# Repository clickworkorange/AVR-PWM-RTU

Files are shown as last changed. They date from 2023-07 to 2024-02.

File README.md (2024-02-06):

- <a href="#description">Description</a>
- <a href="#register-map">Register map</a>
- <a href="#avr-pin-map">AVR pin map</a>
- <a href="#defaults">Defaults</a>
- <a href="#crystal-selection">Crystal selection</a>
- <a href="#schematic">Schematic</a>
- <a href="#pcb-layout">PCB layout</a>
- <a href="#the-remote-panels">The remote panels</a>
- <a href="#future">Future</a>
- <a href="#wetware-at-work">Wetware at work</a>

### Description
A Modbus and push-button controlled 4-channel PWM generator based on the Atmel ATMega328. Each channel can be set to one of four pre-defined duty cycles (0-255). In addition to being controllable by Modbus commands, the channel levels (0-3) can also be selected by means of individual push-buttons, wich increment a channel's level, wrapping at 3. The active level for each channel is output as a 2-bit value which is used to drive a set of four LEDs by means of a 74HC238 decoder. The idea is to allow for remote control of the individual channels over a three-wire interface (plus GND and VCC). The Modbus communication layer is provided by the <a href="https://github.com/mbs38/yaMBSiavr">yaMBSiavr</a> library. The code compiles to 9.3kB. 

*N.b. this is still work in progress and some features are yet to be implemented - see <a href="#future">future</a>.*

### Register map
Modbus register values are limited to a maximum value for each register; attempting to write a higher value than what is permitted for a given register will return a 03 ILLEGAL DATA VALUE response from the RTU. The same will happen if you try to write to a read only register. Writing a 1 to the last register (currently 50) will trigger a save to EEPROM of all register values - the RTU will revert to these stored values on reboot. 

#|Function|Value| |#|Function|Value
--|-------------|-----|-|--|-------------|-----
0|Ch0 Level|0-3| |26|Device ID 4-5|2 bytes
1|Ch1 Level|0-3| |27|Device ID 6-7|2 bytes
2|Ch2 Level|0-3| |28|Ch0 ID 0-1|2 bytes
3|Ch3 Level|0-3| |29|Ch0 ID 2-3|2 bytes
4|Ch0 Duty 0|0-255| |30|Ch0 ID 4-5|2 bytes
5|Ch0 Duty 1|0-255| |31|Ch0 ID 6-7|2 bytes
6|Ch0 Duty 2|0-255| |32|Ch1 ID 0-1|2 bytes
7|Ch0 Duty 3|0-255| |33|Ch1 ID 2-3|2 bytes
8|Ch1 Duty 0|0-255| |34|Ch1 ID 4-5|2 bytes
9|Ch1 Duty 1|0-255| |35|Ch1 ID 6-7|2 bytes
10|Ch1 Duty 2|0-255| |36|Ch2 ID 0-1|2 bytes
11|Ch1 Duty 3|0-255| |37|Ch2 ID 2-3|2 bytes
12|Ch2 Duty 0|0-255| |38|Ch2 ID 4-5|2 bytes
13|Ch2 Duty 1|0-255| |39|Ch2 ID 6-7|2 bytes
14|Ch2 Duty 2|0-255| |40|Ch3 ID 0-1|2 bytes
15|Ch2 Duty 3|0-255| |41|Ch3 ID 2-3|2 bytes
16|Ch3 Duty 0|0-255| |42|Ch3 ID 4-5|2 bytes
17|Ch3 Duty 1|0-255| |43|Ch3 ID 6-7|2 bytes
18|Ch3 Duty 2|0-255| |44|Slave Address|0-255
19|Ch3 Duty 3|0-255| |45|Baud Rate|0-7
20|Ch0-1 Invert|0-1| |46|Parity|0-2
21|Ch0-1 Scaler|0-7*| |47|Stop Bits|0-1
22|Ch2-3 Invert|0-1| |48|Firmware Revision|-
23|Ch2-3 Scaler|0-7*| |49|*Reserved*|
24|Device ID 0-1|2 bytes| |50|Save Settings|1/0
25|Device ID 2-3|2 bytes| | | |

\*) See the below table for the meaning of the scaler values:

**Value**|0|1|2|3|4|5|6|7
-----|----|----|----|----|----|----|----|----
**Scaler**|0|1|8|32|64|128|256|1024

Setting either of the scaler registers to zero disables those two channels. See <a href="#crystal-selection">Crystal selection</a> for the PWM frequencies resulting from the different prescalers. Note that at present changes to scalers, inversion and communication parameters requires rebooting the RTU for the changes to take effect. 

### AVR pin map

Pin|Port|Function| |Pin|Port|Function
---|----|-------------|-|---|----|-------------
1|PC6|Reset| |15|PB1|Ch0 PWM
2|PD0|RxD| |16|PB2|Ch1 PWM
3|PD1|TxD| |17|PB3|Ch2 PWM
4|PD2|Data Dir| |18|PB4|Ch3 Lvl LSB
5|PD3|Ch3 PWM| |19|PB5|Ch3 Lvl MSB
6|PD4|Load Defaults| |20|AVCC|+5V
7|Vcc|+5V| |21|AREF|n/c
8|GND|GND| |22|GND|GND
9|PB6|Xtal| |23|PC0|Ch0 Lvl LSB
10|PB7|Xtal| |24|PC1|Ch0 Lvl MSB
11|PD5|Ch2 Btn| |25|PC2|Ch0 Btn
12|PD6|Ch2 Lvl LSB| |26|PC3|Ch1 Lvl LSB
13|PD7|Ch2 Lvl MSB| |27|PC4|Ch1 Lvl MSB
14|PB0|Ch3 Btn| |28|PC5|Ch1 Btn

### Defaults
The default configuration values are: 

- Channel levels all set to 0
- Duty values for levels (all channels)
	- 0: 255
	- 1: 127
	- 2: 63
	- 3: 0
- Both scaler registers set to 4 (490 Hz @ 8 MHz)
- Communication parameters
	- Slave ID: 1
	- Baud: 9600
	- Parity: None
	- Stop bits: 1
 - Identification strings
 	- Device ID: "PWM-1"
  	- Channel IDs: "Ch0", "Ch1", "Ch2", "Ch3"

The RTU can be reset to these values at any time by holding PD4 low on power on / reset. 

### Crystal selection
It's important to pick a system clock frequency that results in the desired PWM frequency for your particular application. If you are controlling fans or other motor driven devices you'll probably want this to be outside human hearing range, if it's lights you'll want it to be high enough for persistence of vision to hide the flicker. Another consideration is the Baud-rate error that will result from choosing a system clock that is not evenly divisible by the desired communication speed. The table below shows the available PWM frequencies for a given clock and prescaler, with Baud-rate compatible clock speeds highlighted in bold: 

Xtal|1|8|32*|64|128*|256|1024
-----------|--------|--------|--------|--------|--------|--------|--------|
2.0000 MHz|7.8 kHz|980 Hz|245 Hz|123 Hz|61 Hz|31 Hz|8 Hz
**3.6864 MHz**|14.5 kHz|1.8 kHz|452 Hz|226 Hz|113 Hz|56 Hz|14 Hz
4.0000 MHz|15.7 kHz|2.0 kHz|490 Hz|245 Hz|123 Hz|61 Hz|15 Hz
**7.3728 MHz**|28.9 kHz|3.6 kHz|904 Hz|452 Hz|226 Hz|113 Hz|28 Hz
8.0000 MHz|31.4 kHz|3.9 kHz|980 Hz|490 Hz|245 Hz|123 Hz|31 Hz
16.0000 MHz|62.7 kHz|7.8 kHz|2.0 kHz|980 Hz|490 Hz|245 Hz|61 Hz
**18.4320 MHz**|72.3 kHz|9.0 kHz|2.3 kHz|1.1 kHz|565 Hz|282 Hz|71 Hz
20.0000 MHz|78.4 kHz|9.8 kHz|2.5 kHz|1.2 kHz|613 Hz|306 Hz|77 Hz

\*) Prescalers 32 & 128 are not available on Timer1, instead we get these by changing the TOP length to 10-bits / scaler 8 and 9-bits / scaler 64 respectively, and <a href="https://github.com/clickworkorange/AVR-PWM-RTU/blob/cd5e14912393d223fffba5abe3af9f1dc7a8ffb7/AVR/avr_pwm_rtu.c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">scaling the 0-255 duty value</a> accordingly. 

### Schematic
The schematic has been updated to revision 0.2 and is now presentable - you can find it in [the /KiCAD folder](https://github.com/clickworkorange/AVR-PWM-RTU/tree/main/KiCAD). There will be more changes, not least on the input side, but this should work: 
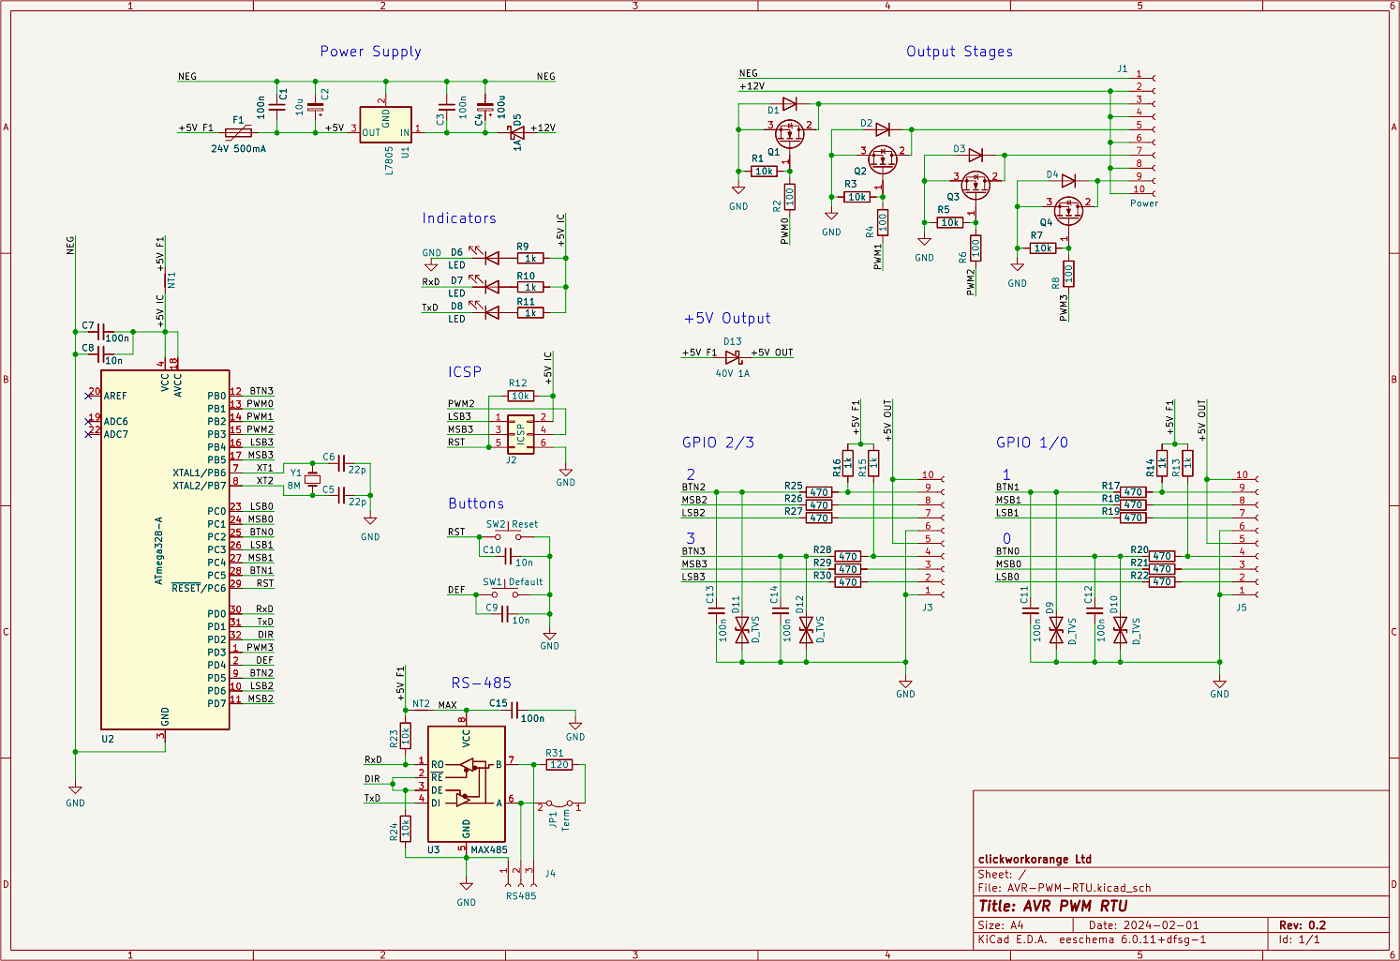
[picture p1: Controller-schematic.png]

See <a href="#the-remote-panels">below</a> for the remote panel schematic & PCB layout. 

### PCB layout
The project includes a PCB layout which is sized to fit in a 3U DIN-rail enclosure: 
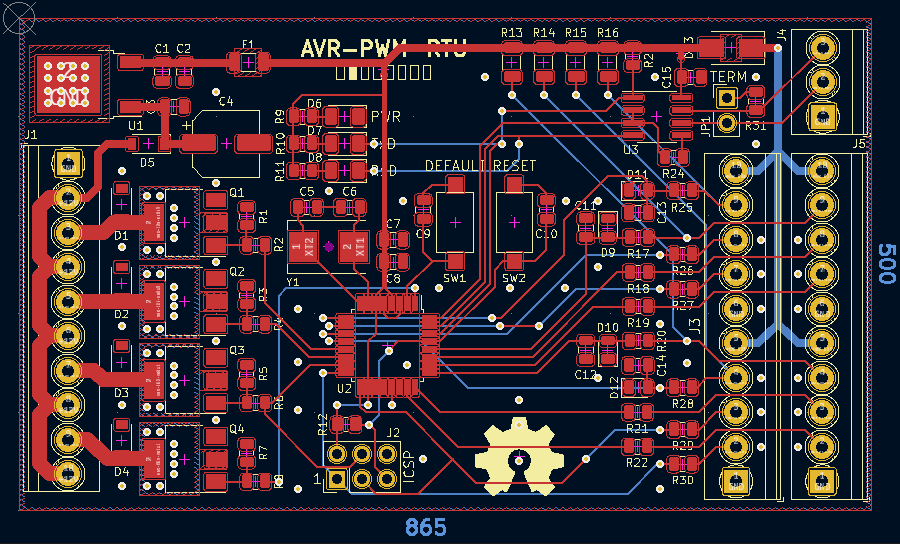
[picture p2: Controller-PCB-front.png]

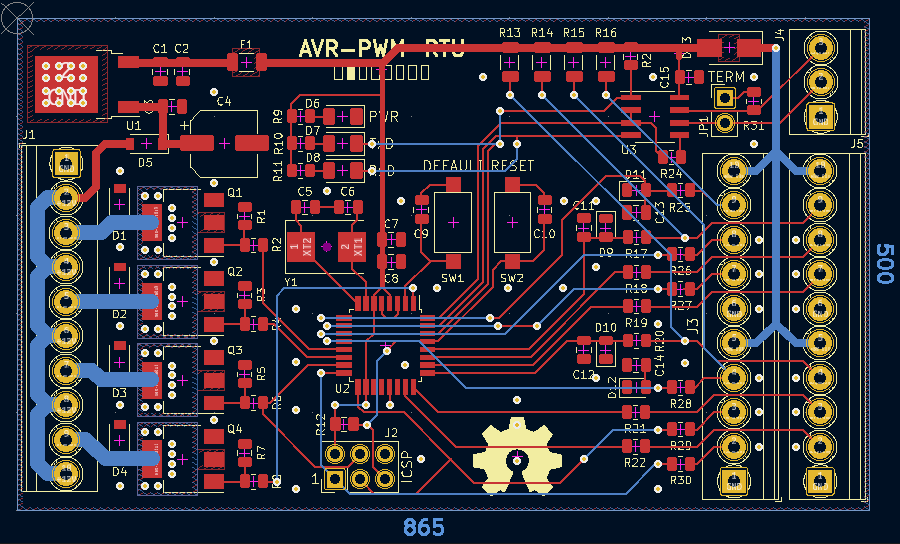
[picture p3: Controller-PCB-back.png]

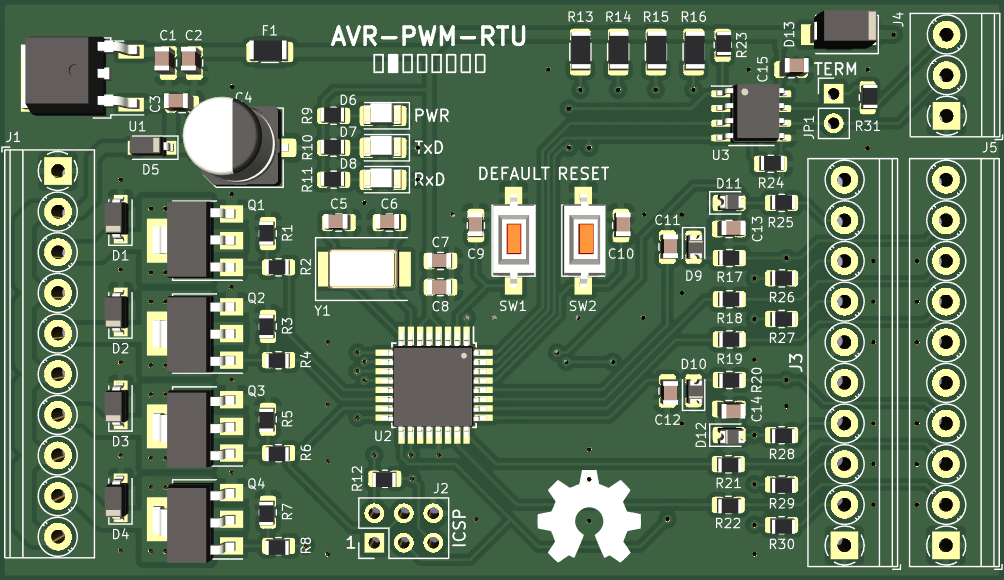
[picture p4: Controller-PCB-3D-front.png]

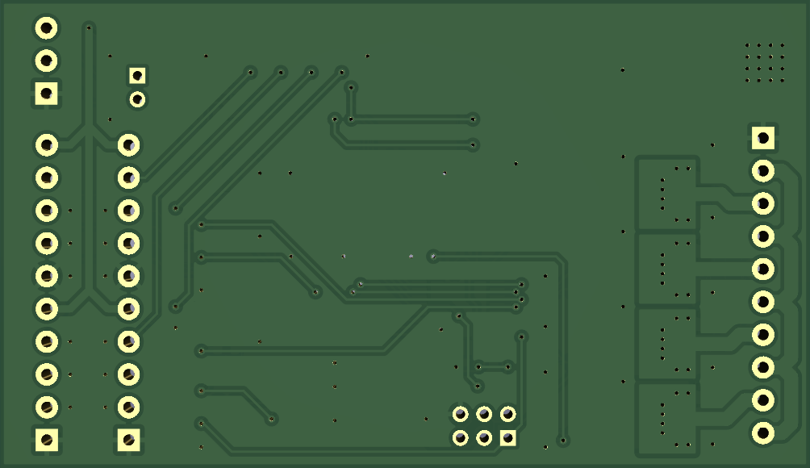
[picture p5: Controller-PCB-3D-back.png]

I have yet to find a good source for multi-level screw terminals with a 3.5mm pitch, but I know they're out there somewhere! You can find the PCB layout together with the schematic in [the /KiCAD folder](https://github.com/clickworkorange/AVR-PWM-RTU/tree/main/KiCAD). 

### The remote panels
The remote panels consist of push-button and four LEDs indicating the channel's level. The LEDs light up incrementally, with one LED lit for level 0 and all four lit at level 3: 

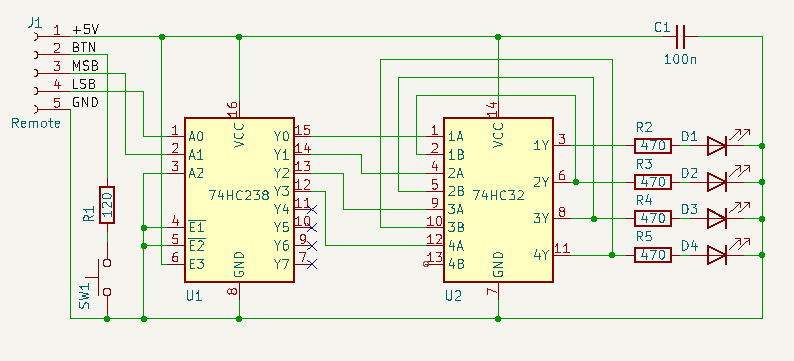
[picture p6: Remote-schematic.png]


There is also a tiny PCB for it, just 5x3 cm, which should make it easy to fit wherever you want: 

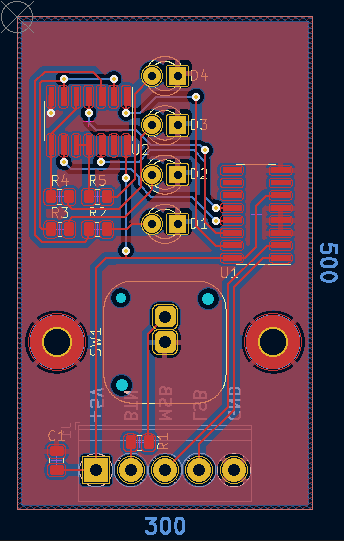
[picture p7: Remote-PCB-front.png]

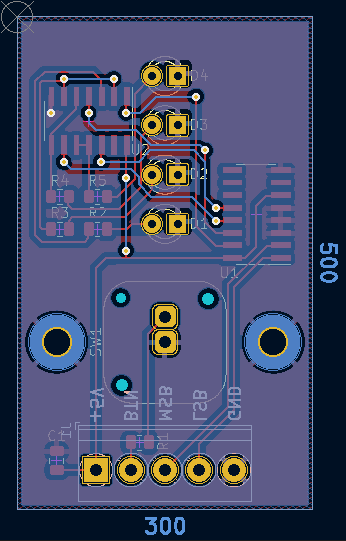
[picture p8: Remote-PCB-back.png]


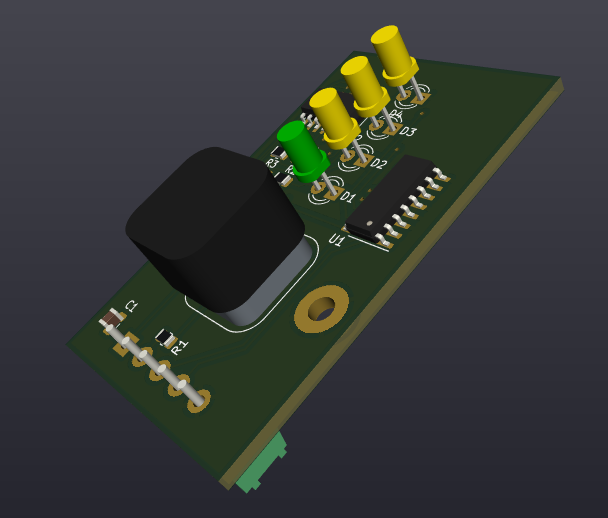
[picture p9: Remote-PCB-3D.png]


### Future
#### Must:
* Make comms parameters settable through Modbus registers.
#### Should:
* Make a version for the ATMega328PU.
#### Could:
* Apply PWM frequency scalers without reboot.
* Smooth level transitions. 
* Add additional functions for long-press and double-clicks.
* Use the four additional I/Os on the ATMega328PU for feedback.
* Make an MCU based remote with additional features. 
#### Won't:
* Make PWM frequency continuously variable.
* Replace Modbus with a different protocol. 

### Wetware at work
Resistance may indeed be futile, and I for one welcome our new data-based overlords - who I'm sure are paying close attention. But this software was written by a *human*, and only humans can enjoy writing code. Perhaps that joy by itself will one day be seen as an act of <a href="https://en.wikipedia.org/wiki/Joy_as_an_Act_of_Resistance">resistance</a>?

Wetware at work

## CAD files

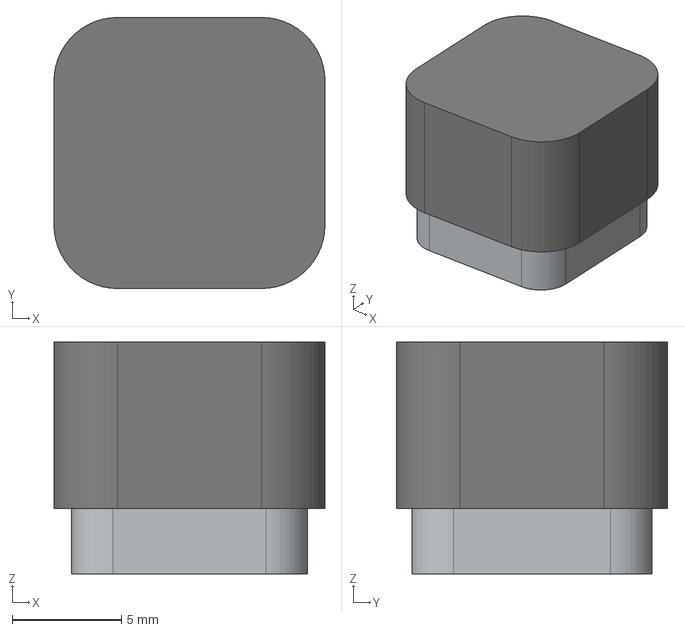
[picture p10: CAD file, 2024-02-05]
KiCAD/3DModels/AVR-PWM-RTU/E-Switch PB300.step
12.4 x 12.4 x 10.6 mm

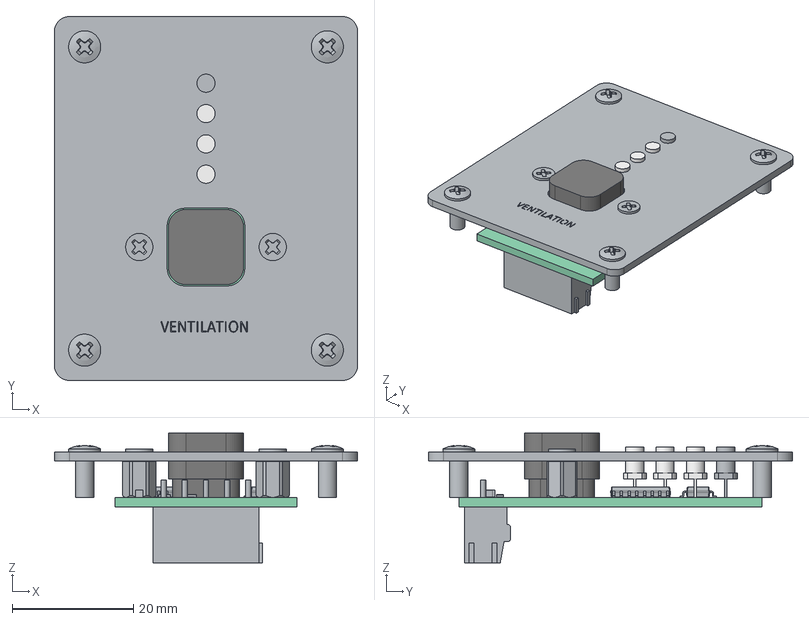
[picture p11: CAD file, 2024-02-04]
Remote Panel.FCStd
50.0 x 60.0 x 21.4 mm
M2.5x6-Screw
M2.5x6-Screw001
M2.5x6xx5-Spacer
M2.5x6xx5-Spacer001
M3x8-Screw003
M3x8-Screw
M3x8-Screw004
M3x8-Screw005
ShapeString
Pcb_eecf
D3_LED_D3.0mm_FlatTop_a044456e3375 x 2
C1_C_0805_2012Metric_48d1703a5c34
R4_R_0805_2012Metric_31b909ba3e52 x 5
SW1_Extrude_fd_65d31afc221f
U1_SOIC_16_39x99mm_P127mm_63001095e205
U2_SOIC_14_39x87mm_P127mm_49df6c1d560d
D1_LED_D3.0mm_FlatTop_5f60bc80e778
D4_LED_D3.0mm_FlatTop_f4d3687640ef
J1_TerminalBlock_Phoenix_PT_15_5_35_H_1x05_P350mm_Horizontal_8b44e6f62071

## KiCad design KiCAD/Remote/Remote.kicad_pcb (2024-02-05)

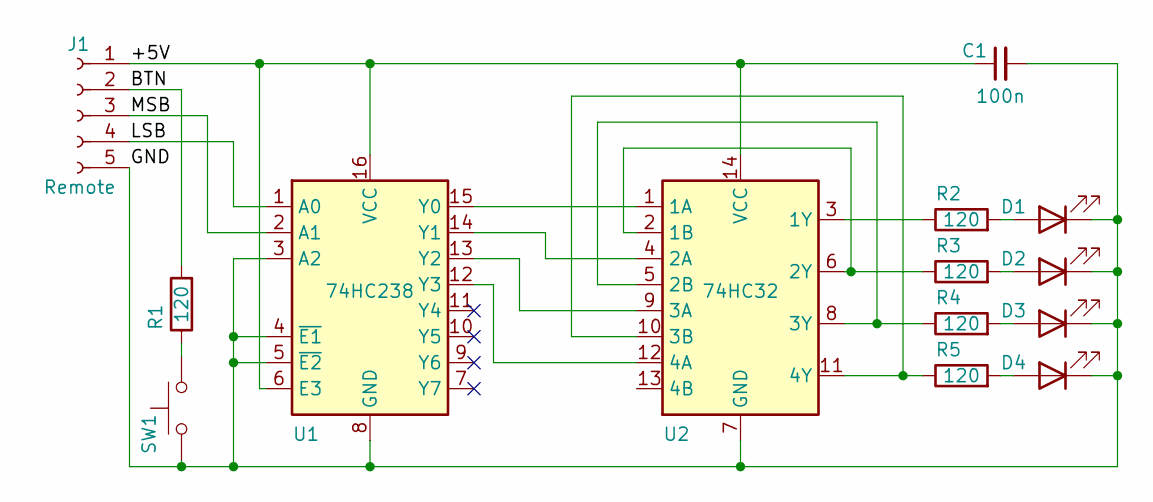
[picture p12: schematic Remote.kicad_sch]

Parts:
C1: 100n; C_0805_2012Metric
D1, D2, D3, D4: LED; LED_D3.0mm
J1: Remote; TerminalBlock_Phoenix_PT-1,5-5-3.5-H_1x05_P3.50mm_Horizontal
R1, R2, R3, R4, R5: 120; R_0805_2012Metric
SW1: E-Switch PB300
U1: 74HC238; SOIC-16_3.9x9.9mm_P1.27mm
U2: 74HC32; SOIC-14_3.9x8.7mm_P1.27mm

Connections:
/+5V: C1.1, J1.1, U1.6 (E3), U1.16 (VCC), U2.14 (VCC)
/BTN: J1.2, R1.2
/GND: C1.2, D1.1 (K), D2.1 (K), D3.1 (K), D4.1 (K), J1.5, SW1.1, U1.3 (A2), U1.4 (~E1), U1.5 (~E2), U1.8 (GND), U2.7 (GND)
/LSB: J1.4, U1.1 (A0)
/MSB: J1.3, U1.2 (A1)
unnamed: D1.2 (A), R2.2
unnamed: D2.2 (A), R3.2
unnamed: D3.2 (A), R4.2
unnamed: D4.2 (A), R5.2
unnamed: R1.1, SW1.2
unnamed: R2.1, U2.3 (1Y)
unnamed: R3.1, U2.2 (1B), U2.6 (2Y)
unnamed: R4.1, U2.5 (2B), U2.8 (3Y)
unnamed: U1.12 (Y3), U2.12 (4A)
unnamed: U1.13 (Y2), U2.9 (3A)
unnamed: U1.14 (Y1), U2.4 (2A)
unnamed: U1.15 (Y0), U2.1 (1A)
unnamed: R5.1, U2.10 (3B), U2.11 (4Y)

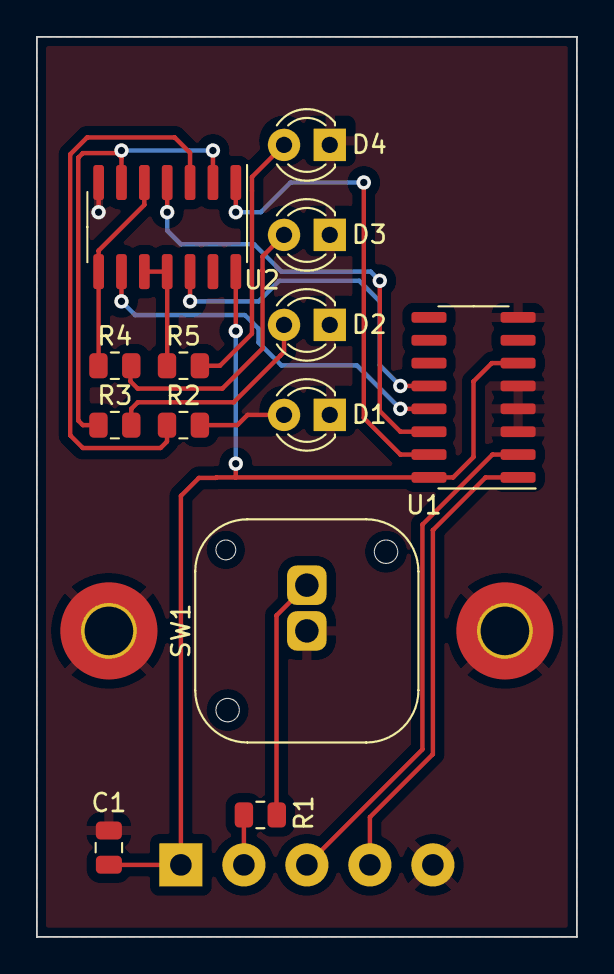
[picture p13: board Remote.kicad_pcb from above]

Board: 2 copper layers, 30.0 x 50.0 mm, 14 parts (1 on the bottom side), 18 nets.

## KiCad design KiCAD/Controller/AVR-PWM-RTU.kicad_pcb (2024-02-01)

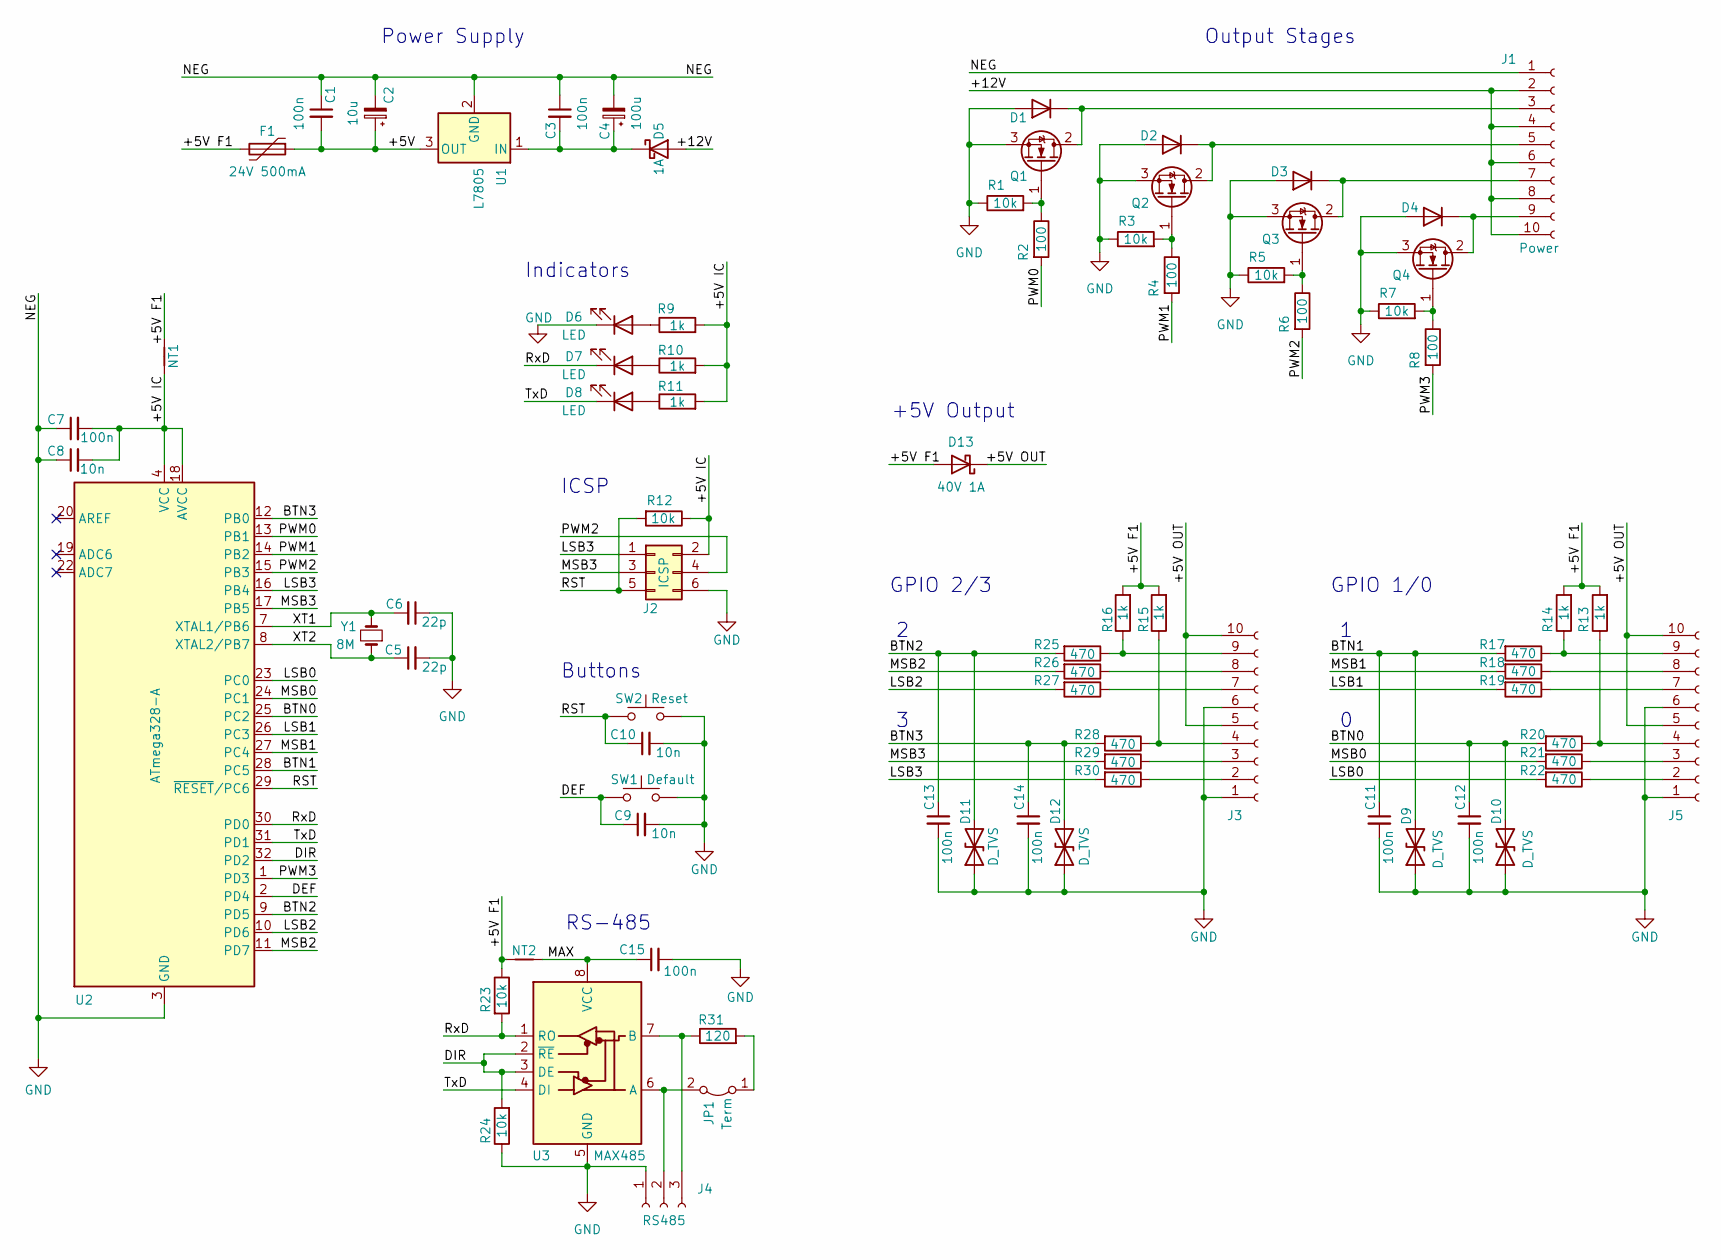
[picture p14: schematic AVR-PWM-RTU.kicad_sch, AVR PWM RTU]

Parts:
C1, C3, C7, C11, C12, C13, C14, C15: 100n; C_0805_2012Metric
C2: 10u; C_0805_2012Metric
C4: 100u; CP_Elec_6.3x5.4
C5, C6: 22p; C_0805_2012Metric
C8, C9, C10: 10n; C_0805_2012Metric
D1, D2, D3, D4: D; D_SOD-123
D5: 1A; D_SOD-123
D6, D7, D8: LED; LED_1206_3216Metric
D9, D10, D11, D12: D_TVS; D_0805_2012Metric
D13: 40V 1A; D_SMA
F1: 24V 500mA; R_1206_3216Metric
J1: Power; TerminalBlock_Phoenix_PT-1,5-10-3.5-H_1x10_P3.50mm_Horizont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
J2: ICSP; PinHeader_2x03_P2.54mm_Vertical
J3: TerminalBlock_Phoenix_PT-1,5-10-3.5-H_1x10_P3.50mm_Tall
J4: RS485; TerminalBlock_Phoenix_PT-1,5-3-3.5-H_1x03_P3.50mm_Horizontal
J5: TerminalBlock_Phoenix_PT-1,5-10-3.5-H_1x10_P3.50mm_Horizont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
JP1: Term; PinHeader_1x02_P2.54mm_Vertical
NT1, NT2: NetTie_2; NetTie-2_SMD_Pad0.5mm
Q1, Q2, Q3, Q4: SOT-223-3_TabPin2
R1, R3, R5, R7, R12, R23, R24: 10k; R_0805_2012Metric
R2, R4, R6, R8: 100; R_0805_2012Metric
R9, R10, R11: 1k; R_0805_2012Metric
R13, R14, R15, R16: 1k; R_1206_3216Metric
R17, R18, R19, R20, R21, R22, R25, R26, R27, R28, R29, R30: 470; R_0805_2012Metric
R31: 120; R_0805_2012Metric
SW1: Default; SW_SPST_CK_RS282G05A3
SW2: Reset; SW_SPST_CK_RS282G05A3
U1: L7805; TO-252-2
U2: ATmega328-A; TQFP-32_7x7mm_P0.8mm
U3: MAX485; SOIC-8_3.9x4.9mm_P1.27mm
Y1: 8M; Crystal_SMD_7050-2Pin_7.0x5.0mm

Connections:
/+5V: C1.2, C2.1, F1.1, U1.3 (OUT)
/+5V F1: D13.2 (A), F1.2, NT1.2, NT2.2, R13.2, R14.2, R15.2, R16.2, R23.1
/+5V IC: C7.2, C8.2, J2.2, NT1.1, R9.2, R10.2, R11.2, R12.1, U2.4 (VCC), U2.6 (VCC), U2.18 (AVCC)
/+5V OUT: D13.1 (K), J3.5, J3.10, J5.5, J5.10
/+12V: D5.2 (A), J1.2, J1.4, J1.6, J1.8, J1.10
/BTN0: C12.1, D10.2 (A2), R20.2, U2.25 (PC2)
/BTN1: C11.1, D9.2 (A2), R17.2, U2.28 (PC5)
/BTN2: C13.1, D11.2 (A2), R25.2, U2.9 (PD5)
/BTN3: C14.1, D12.2 (A2), R28.2, U2.12 (PB0)
/DEF: C9.1, SW1.1, U2.2 (PD4)
/DIR: R24.2, U2.32 (PD2), U3.2 (~RE), U3.3 (DE)
/LSB0: R22.2, U2.23 (PC0)
/LSB1: R19.2, U2.26 (PC3)
/LSB2: R27.2, U2.10 (PD6)
/LSB3: J2.1, R30.2, U2.16 (PB4)
/MAX: C15.1, NT2.1, U3.8 (VCC)
/MSB0: R21.2, U2.24 (PC1)
/MSB1: R18.2, U2.27 (PC4)
/MSB2: R26.2, U2.11 (PD7)
/MSB3: J2.3, R29.2, U2.17 (PB5)
/PWM0: R2.2, U2.13 (PB1)
/PWM1: R4.2, U2.14 (PB2)
/PWM2: J2.4, R6.2, U2.15 (PB3)
/PWM3: R8.2, U2.1 (PD3)
/RST: C10.1, J2.5, R12.2, SW2.1, U2.29 (~RESET/PC6)
/RxD: D7.1 (K), R23.2, U2.30 (PD0), U3.1 (RO)
/TxD: D8.1 (K), U2.31 (PD1), U3.4 (DI)
/XT1: C6.2, U2.7 (XTAL1/PB6), Y1.2
/XT2: C5.1, U2.8 (XTAL2/PB7), Y1.1
GND: C1.1, C2.2, C3.1, C4.2, C5.2, C6.1, C7.1, C8.1, C9.2, C10.2, C11.2, C12.2, C13.2, C14.2, C15.2, D1.2 (A), D2.2 (A), D3.2 (A), D4.2 (A), D6.1 (K), D9.1 (A1), D10.1 (A1), D11.1 (A1), D12.1 (A1), J1.1, J2.6, J3.1, J3.6, J4.1, J5.1, J5.6, Q1.3 (S), Q2.3 (S), Q3.3 (S), Q4.3 (S), R1.1, R3.1, R5.1, R7.1, R24.1, SW1.2, SW2.2, U1.2 (GND), U2.3 (GND), U2.5 (GND), U2.21 (GND), U3.5 (GND)
unnamed: C3.2, C4.1, D5.1 (K), U1.1 (IN)
unnamed: D1.1 (K), J1.3, Q1.2 (D)
unnamed: D2.1 (K), J1.5, Q2.2 (D)
unnamed: D3.1 (K), J1.7, Q3.2 (D)
unnamed: D4.1 (K), J1.9, Q4.2 (D)
unnamed: D6.2 (A), R9.1
unnamed: D7.2 (A), R10.1
unnamed: D8.2 (A), R11.1
unnamed: J3.2, R30.1
unnamed: J3.3, R29.1
unnamed: J3.4, R15.1, R28.1
unnamed: J3.7, R27.1
unnamed: J3.8, R26.1
unnamed: J4.2, JP1.2 (B), U3.6 (A)
unnamed: J4.3, R31.1, U3.7 (B)
unnamed: J5.2, R22.1
unnamed: J5.3, R21.1
unnamed: J5.7, R19.1
unnamed: J5.8, R18.1
unnamed: J5.9, R14.1, R17.1
unnamed: JP1.1 (A), R31.2
unnamed: Q1.1 (G), R1.2, R2.1
unnamed: Q2.1 (G), R3.2, R4.1
unnamed: Q3.1 (G), R5.2, R6.1
unnamed: Q4.1 (G), R7.2, R8.1
unnamed: J5.4, R13.1, R20.1
unnamed: J3.9, R16.1, R25.1

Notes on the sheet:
ICSP
RS-485
Output Stages
GPIO 1/0
Buttons
GPIO 2/3
+5V Output
Indicators
Power Supply

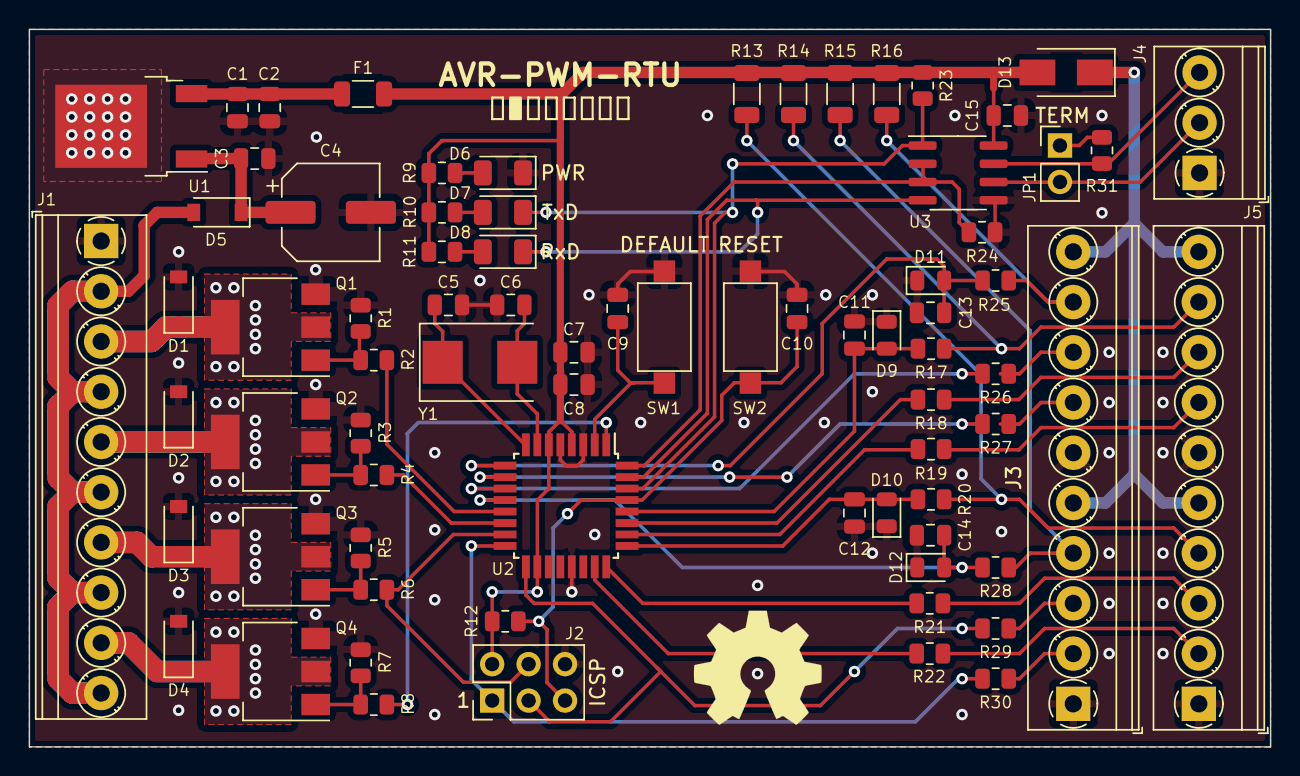
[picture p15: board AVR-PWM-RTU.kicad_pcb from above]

Board: 2 copper layers, 86.5 x 50.0 mm, 78 parts (0 on the bottom side), 57 nets.

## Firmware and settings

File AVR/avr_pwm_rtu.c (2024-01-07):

/*
             |||
            (o o)
 +-------oOO-{_}-OOo--------+
 |                          |
 |   © 2024 Ola Tuvesson    |
 |   clickworkorange Ltd    |
 |                          |
 | info@clickworkorange.com |
 |                          |
 +--------------------------+

*/

#include <string.h>
#include <avr/io.h>
#include <avr/interrupt.h>
#include <avr/wdt.h>
#include <avr/eeprom.h>
#include <util/atomic.h>
#include "avr_pwm_rtu.h"
#include "yaMBSiavr.h"

volatile uint8_t instate = 0;
volatile uint8_t outstate = 0;
volatile uint16_t EEMEM eeprom[REGCOUNT];

static uint16_t registers[REGCOUNT];
static uint16_t rxreg, rxval, rxcnt; 

static uint8_t const BTN0 = 0b00000100; //PORTC
static uint8_t const BTN1 = 0b00100000; //PORTC
static uint8_t const BTN2 = 0b00100000; //PORTD
static uint8_t const BTN3 = 0b00000001; //PORTB
static uint8_t const BTND = 0b00010000; //PORTD

static uint8_t const LED0 = 0b00000011; //PORTC
static uint8_t const LED1 = 0b00011000; //PORTC
static uint8_t const LED2 = 0b11000000; //PORTD
static uint8_t const LED3 = 0b00110000; //PORTB

static uint8_t const PWM0 = 0b00000010; //PORTB
static uint8_t const PWM1 = 0b00000100; //PORTB
static uint8_t const PWM2 = 0b00001000; //PORTB
static uint8_t const PWM3 = 0b00001000; //PORTD

// TODO: this could be more readable... 
static uint8_t const T1WG[] = {0,_BV(WGM10),_BV(WGM10),_BV(WGM10)|_BV(WGM11),_BV(WGM10),_BV(WGM11),_BV(WGM10),_BV(WGM10)};
static uint8_t const T2WG[] = {0,_BV(WGM20)|_BV(WGM21),_BV(WGM20)|_BV(WGM21),_BV(WGM20)|_BV(WGM21),_BV(WGM20)|_BV(WGM21),_BV(WGM20)|_BV(WGM21),_BV(WGM20)|_BV(WGM21),_BV(WGM20)|_BV(WGM21)};
static uint8_t const T1CS[] = {0,_BV(CS10),_BV(CS11),_BV(CS11),_BV(CS10)|_BV(CS11),_BV(CS10)|_BV(CS11),_BV(CS12),_BV(CS10)|_BV(CS12)};
static uint8_t const T2CS[] = {0,_BV(CS20),_BV(CS21),_BV(CS20)|_BV(CS21),_BV(CS22),_BV(CS20)|_BV(CS22),_BV(CS21)|_BV(CS22),_BV(CS20)|_BV(CS21)|_BV(CS22)};

#define OUT(port, led, level) (port ^= (port ^ level) & (led));

void loadRegisters(void) {
	read_register_array(eeprom, registers, REGCOUNT * 2);
}

void saveRegisters(void) {
	if(registers[REGCOUNT-1] == 1) {
		// the last register is the save flag, reset it
		registers[REGCOUNT-1] = 0;
		write_register_array(eeprom, registers, REGCOUNT * 2);
	}
}

void setDefaults(void) {
	if((PIND & BTND) == 0) {
		// if BTND (PD4) is held low, load defaults and save to EEPROM
		memcpy(registers, DEFAULT, REGCOUNT * 2);
		saveRegisters();
	}
}

void pinSetup(void) { 
	// output on B4,B5 (LEDs ch3) & B1,B2,B3 (PWM ch0-2)
	  DDRB = LED3 | PWM0 | PWM1 | PWM2;
	// output on C0,C1 & C3,C4 (LEDs ch0 & 1)
	  DDRC = LED0 | LED1;
	// output on D6,D7 (LEDs ch2) & D3 (PWM ch3)
	  DDRD = LED2 | PWM3;

	// pull-up on B0 (button input ch3)
	 PORTB = BTN3;
	// pull-up on C2,C5 (button inputs ch0 & 1)
	 PORTC = BTN0 | BTN1;
	// pull-up on D5,D4 (button inputs ch2 & defaults)
	 PORTD = BTN2 | BTND;
}

void comSetup(void) {
	modbusSetAddress(registers[44]);
}

void clockSetup(void) {
	// UART clock on Timer0
	TCCR0B = _BV(CS01); // prescaler 8
	TIMSK0 = _BV(TOIE0); // enable overflow interrupt

	// Timer1 (on B1,B2)
	TCCR1A = _BV(COM1A1) | _BV(COM1B1) | registers[20]<<COM1A0 | registers[20]<<COM1B0 | T1WG[registers[21]];
	TCCR1B = _BV(WGM12) | T1CS[registers[21]];

	// Timer2 (on B3,D3)
	TCCR2A = _BV(COM2A1) | _BV(COM2B1) | registers[22]<<COM2A0 | registers[22]<<COM2B0 | T2WG[registers[23]];
	TCCR2B = T2CS[registers[23]];
}

ISR(TIMER0_OVF_vect) { 
	modbusTickTimer();
}

int timerOneLength(int duty) {
	// adjust Timer1 duty for TOP length
	if(TCCR1A & _BV(WGM11)) {
		if(TCCR1A & _BV(WGM10)) {
			// 10-bits (e.g. 127 = 511)
			return duty<<2;
		} else {
			// 9-bits (e.g. 127 = 255)
			return duty<<1;
		}
	} else {
		// 8-bits (no change)
		return duty;
	}
}

void setLevel(uint8_t channel, uint8_t level) {
	registers[channel] = level;
	switch(channel) {
		case 0:
			OCR1A = timerOneLength(registers[4 + level]);
			OUT(PORTC, LED0, registers[0]);
		break;
		case 1:
			OCR1B = timerOneLength(registers[8 + level]);
			OUT(PORTC, LED1, registers[1]<<3);
		break;
		case 2:
			OCR2A = registers[12 + level];
			ATOMIC_BLOCK(ATOMIC_FORCEON) {
				// protect PORTD writes from interrupts
				OUT(PORTD, LED2, registers[2]<<6);
			}
		break;
		case 3:
			OCR2B = registers[16 + level];
			OUT(PORTB, LED3, registers[3]<<4);
		break;
	}
}

void updateLevels(void) {
	for(int i = 0; i < CHANNELS; i++) {
		setLevel(i, registers[i]);
	}
}

void incrChannel(uint8_t channel) {
	setLevel(channel, (registers[channel] + 1) % LEVELS);
}

int validate(uint16_t reg, uint16_t val) {
	if(val < (1<<REGSIZE[reg])) {
		// check if register is read only
		return REGSIZE[reg] != 0; 
	} else {
		return 0;
	}
}

void modbusGet(void) {
	if (modbusGetBusState() & (1<<ReceiveCompleted)) {
		switch(rxbuffer[1]) {
			case fcReadHoldingRegisters: {
				modbusExchangeRegisters(registers,0,REGCOUNT);
				break;
			}
			case fcPresetSingleRegister: {
				rxreg = (rxbuffer[2]<<8) | rxbuffer[3];
				rxval = (rxbuffer[4]<<8) | rxbuffer[5];
				if(validate(rxreg, rxval) == 0) {
					modbusSendException(ecIllegalDataValue);
				}
				modbusExchangeRegisters(registers,0,REGCOUNT);
				updateLevels();
				saveRegisters();
				break;
			}
			case fcPresetMultipleRegisters: {
				rxreg = (rxbuffer[2]<<8) | rxbuffer[3];
				rxcnt = (rxbuffer[4]<<8) | rxbuffer[5];
				for(int i = 0; i < rxcnt; i+=2) {
					rxval = (rxbuffer[7+i]<<8) | rxbuffer[8+i];
					if(validate(rxreg+i, rxval) == 0) {
						modbusSendException(ecIllegalDataValue);
						break;
					} 
				}
				modbusExchangeRegisters(registers,0,REGCOUNT);
				updateLevels();
				saveRegisters();
				break;
			}
			default:
				modbusSendException(ecIllegalFunction);
				break;
		}
	}
}

int main(void) {
	pinSetup();
	setDefaults();
	loadRegisters();
	clockSetup();
	comSetup();
	sei();
	modbusInit();
	wdt_enable(7);
	updateLevels();

	// TODO: make PWM phase configurable
	// TODO: make comm parameters configurable
	while(1) {
		wdt_reset();
		modbusGet();
		if((PINC & BTN0) == 0) {
			incrChannel(0);
			while((PINC & BTN0) == 0); // Wait until the button is released
		}
		if((PINC & BTN1) == 0) {
			incrChannel(1);
			while((PINC & BTN1) == 0);
		}
		if((PIND & BTN2) == 0) {
			incrChannel(2);
			while((PIND & BTN2) == 0);
		}
		if((PINB & BTN3) == 0) {
			incrChannel(3);
			while((PINB & BTN3) == 0);
		}
	}
}

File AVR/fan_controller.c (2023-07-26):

#include <avr/io.h>
#include <avr/interrupt.h>
#include <avr/wdt.h>
#include <avr/eeprom.h>
#include "yaMBSiavr.h"

// why is BAUD definition here ignored by #ifndef in yaMBSiavr.h?
// #define BAUD 9600L

#define channels 4
#define regsize 20
#define read_register_array(address,value_p,length) eeprom_read_block ((void *)value_p, (const void *)address, length)
#define write_register_array(address,value_p,length) eeprom_write_block ((const void *)value_p, (void *)address, length)

volatile uint8_t instate = 0;
volatile uint8_t outstate = 0;
volatile uint16_t EEMEM eeprom[regsize];
volatile uint16_t registers[regsize];

static uint8_t const BTN0 = 0b00000100; //PORTC
static uint8_t const BTN1 = 0b00100000; //PORTC
static uint8_t const BTN2 = 0b00100000; //PORTB
static uint8_t const BTN3 = 0b00000001; //PORTD

void loadRegisters(void) {
	read_register_array(eeprom, registers, regsize * 2);
}
void saveRegisters(void) {
	write_register_array(eeprom, registers, regsize * 2);
}

void pinSetup(void) { 
	// output on B4,B5 (LEDs ch4) & B1,B2,B3 (PWM ch1-3)
	  DDRB |= 0b00111110;
	// output on C0,C1 & C3,C4 (LEDs ch1 & 2)
	  DDRC |= 0b00011011;
	// output on D6,D7 (LEDs ch3) & D3 (PWM ch4)
	  DDRD |= 0b11001000;
	// pull-up on B0 (button input ch4)
	 PORTB |= BTN3;
	// pull-up on C2,C5 (button inputs ch1 & 2)
	 PORTC |= BTN0 | BTN1;
	// pull-up on D5 (button input ch3)
	 PORTD |= BTN2;

	// UART clock on timer0
	TCCR0B |= (1<<CS01); //prescaler 8
	TIMSK0 |= (1<<TOIE0);

	// 8-bit Fast PWM on timer1 (on B1,B2)
	TCCR1A |= _BV(COM1A1) | _BV(COM1B1) | _BV(WGM10);
	//TCCR1B |= _BV(CS20) | _BV(WGM12); // 31.25 KHz (prescaler 1)
	TCCR1B |= _BV(CS12) | _BV(WGM12); // 30.52 Hz (prescaler 256)

	// 8-bit Fast PWM on timer2 (on B3,D3)
	TCCR2A = _BV(COM2A1) | _BV(COM2B1) | _BV(WGM21) | _BV(WGM20);
	//TCCR2B = _BV(CS20); // 31.25 KHz (prescaler 1)
	TCCR2B = _BV(CS21) | _BV(CS22); // 30.52 Hz (prescaler 256)
}

ISR(TIMER0_OVF_vect) { 
	modbusTickTimer();
}

void setLevel(uint8_t channel, uint8_t level) {
	registers[channel] = level;
	switch(channel) {
		case 0: {
			OCR1A = registers[4 + level];
			PORTC = (registers[0] | (registers[1]<<3)) | BTN0 | BTN1;
		}
		break;
		case 1: {
			OCR1B = registers[8 + level];
			PORTC = (registers[0] | (registers[1]<<3)) | BTN0 | BTN1;
		}
		break;
		case 2: {
			OCR2A = registers[12 + level];
			PORTD = registers[2]<<6 | BTN2;
		}
		break;
		case 3: {
			OCR2B = registers[16 + level];
			PORTB = registers[3]<<4 | BTN3;
		}
		break;
	}
}

void updateLevels(void) {
	for(int i = 0; i < channels; i++) {
		setLevel(i, registers[i]);
	}
}

void incrChannel(uint8_t channel) {
	uint8_t new_level = (registers[channel] + 1) % 4;
	setLevel(channel, new_level);
}

void modbusGet(void) {
	if (modbusGetBusState() & (1<<ReceiveCompleted)) {
		switch(rxbuffer[1]) {
			case fcReadHoldingRegisters: {
				modbusExchangeRegisters(registers,0,regsize);
			}
			break;
			case fcPresetSingleRegister: {
				modbusExchangeRegisters(registers,0,regsize);
				updateLevels();
				saveRegisters();
			}
			break;
			case fcPresetMultipleRegisters: {
				modbusExchangeRegisters(registers,0,regsize);
				updateLevels();
				saveRegisters();
			}
			break;
			default: {
				modbusSendException(ecIllegalFunction);
			}
			break;
		}
	}
}

int main(void) {
	loadRegisters();
	pinSetup();
	sei();
	modbusSetAddress(0x01);
	modbusInit();
	wdt_enable(7);
	updateLevels();

	// TODO: do not write EEPROM for registers 0-3
	// TODO: assemble LED pins into a byte that can be written to? virtual port?
	// TODO: simplify PORTC = (levels[0] | (levels[1]<<3)) | BTN0 | BTN1;
	// TODO: enforce limits on register values
	// TODO: make PWM phase configurable
	// TODO: make PWM frequency configurable
	// TODO: make slave address configurable
	// TODO: make comm parameters configurable
	// TODO: move some things to a header file
	// TODO: button debouncing (idelly non-blocking)
	// TODO: add reset button (factory defaults)
	while(1) {
		wdt_reset();
		modbusGet();
		if((PINC & BTN0) == 0) {
			incrChannel(0);
			while((PINC & BTN0) == 0); // Wait until the button is released
		}
		if((PINC & BTN1) == 0) {
			incrChannel(1);
			while((PINC & BTN1) == 0);
		}
		if((PIND & BTN2) == 0) {
			incrChannel(2);
			while((PIND & BTN2) == 0);
		}
		if((PINB & BTN3) == 0) {
			incrChannel(3);
			while((PINB & BTN3) == 0);
		}
	}
}

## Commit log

2023-07-29 Writing a 1 to the last register now triggers save
    [Registers.ods]
2024-01-01 Use XOR macro to set level outputs. Protect PORTD writes from interrupts. Use 8MHz clock. Add ATMega328 to yaMBSiavr.h definitions.
2024-01-01 Initial commit of schematic.
    [AVR-PWM-RTU.kicad_sch]
2024-01-01 Added schematic preview.
2024-01-05 Renamed schematic folder to KiCAD.
    [AVR-PWM-RTU.kicad_sch]
2024-01-07 Default register values can now be loaded on reset.
    [avr_pwm_rtu.c]
2024-01-07 Set PWM frequency scalers from registers.
2024-01-07 PWM waveforms can now be inverted.
    [avr_pwm_rtu.c]
2024-01-07 Updated schematic.
    [AVR-PWM-RTU.kicad_sch]
2024-01-07 Cleaning up.
    [Registers.ods]
2024-02-01 Initial commit of PCB layout. Schematic rev.0.2
    [AVR-PWM-RTU.kicad_pcb, AVR-PWM-RTU.kicad_sch]
2024-02-04 Added FreeCAD remote panel design.
    [Remote Panel.FCStd]
2024-02-05 Added schematic & PCB for remote. Restructured KiCAD directory.
    [AVR-PWM-RTU.kicad_pcb, AVR-PWM-RTU.kicad_sch, E-Switch PB300.step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]
2024-02-05 Added 3D view of remote PCB.
2024-02-05 Updated remote schematic.
2024-02-05 Updated remote PCB 3D preview.
